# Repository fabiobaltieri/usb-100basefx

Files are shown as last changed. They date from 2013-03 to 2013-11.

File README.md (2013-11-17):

USB to 100BASE-FX
==================

http://fabiobaltieri.com/2013/05/26/usb-to-100base-fx-optical-fiber-network-card/

This project is an Open-Hardware USB to 100BASE-FX fiber optic network card,
based on an ASIX AX88772B USB to Fast Ethernet controller, and comes in two
variants for the fiber transciver.

License
-------

This work is licensed under a Creative Commons Attribution-ShareAlike 3.0
License.

Contents
--------

    README        this file
    docs/         datasheets and documentation
    scsc/         source directory for the 1x9 hardware variant
    sfp/          source directory for the SFP hardware variant
    eeprom-notes  some notes and snippets on device configuration

Hardware
--------

All hardware files (schematic, layout and libraries) are in CadSoft Eagle
format.

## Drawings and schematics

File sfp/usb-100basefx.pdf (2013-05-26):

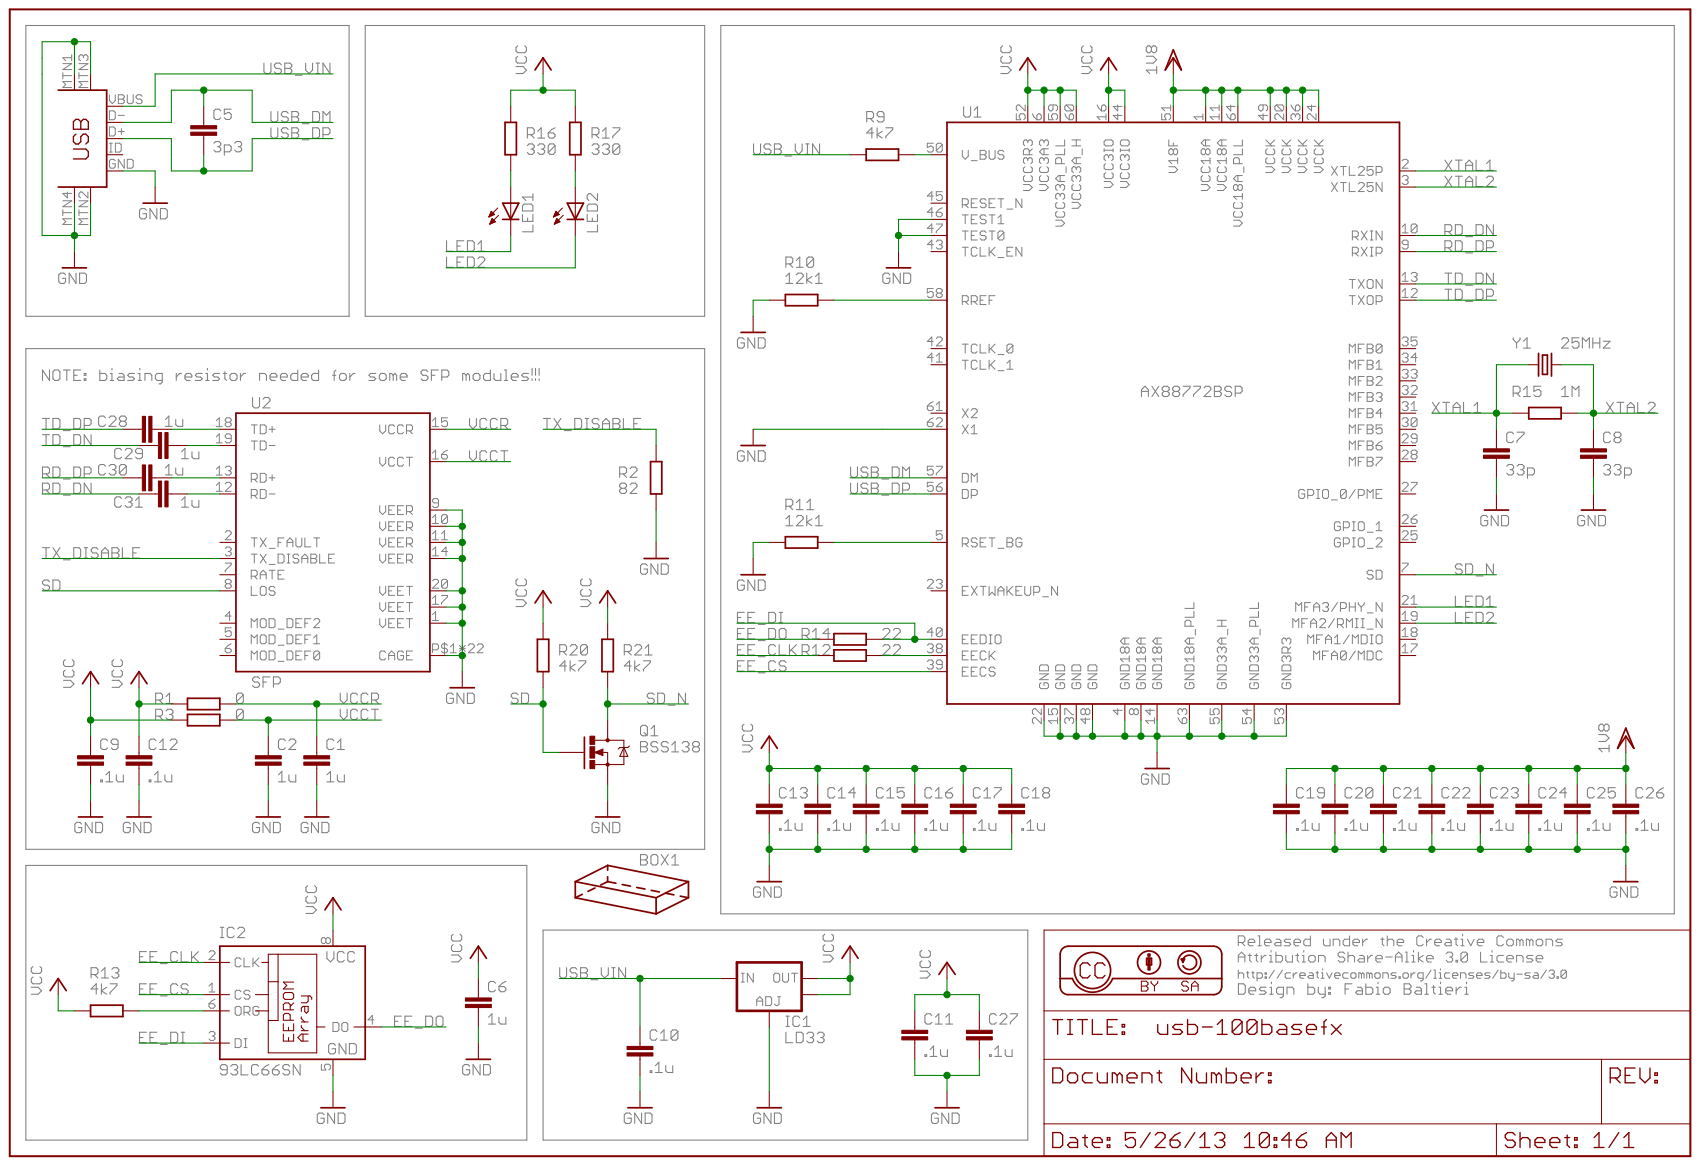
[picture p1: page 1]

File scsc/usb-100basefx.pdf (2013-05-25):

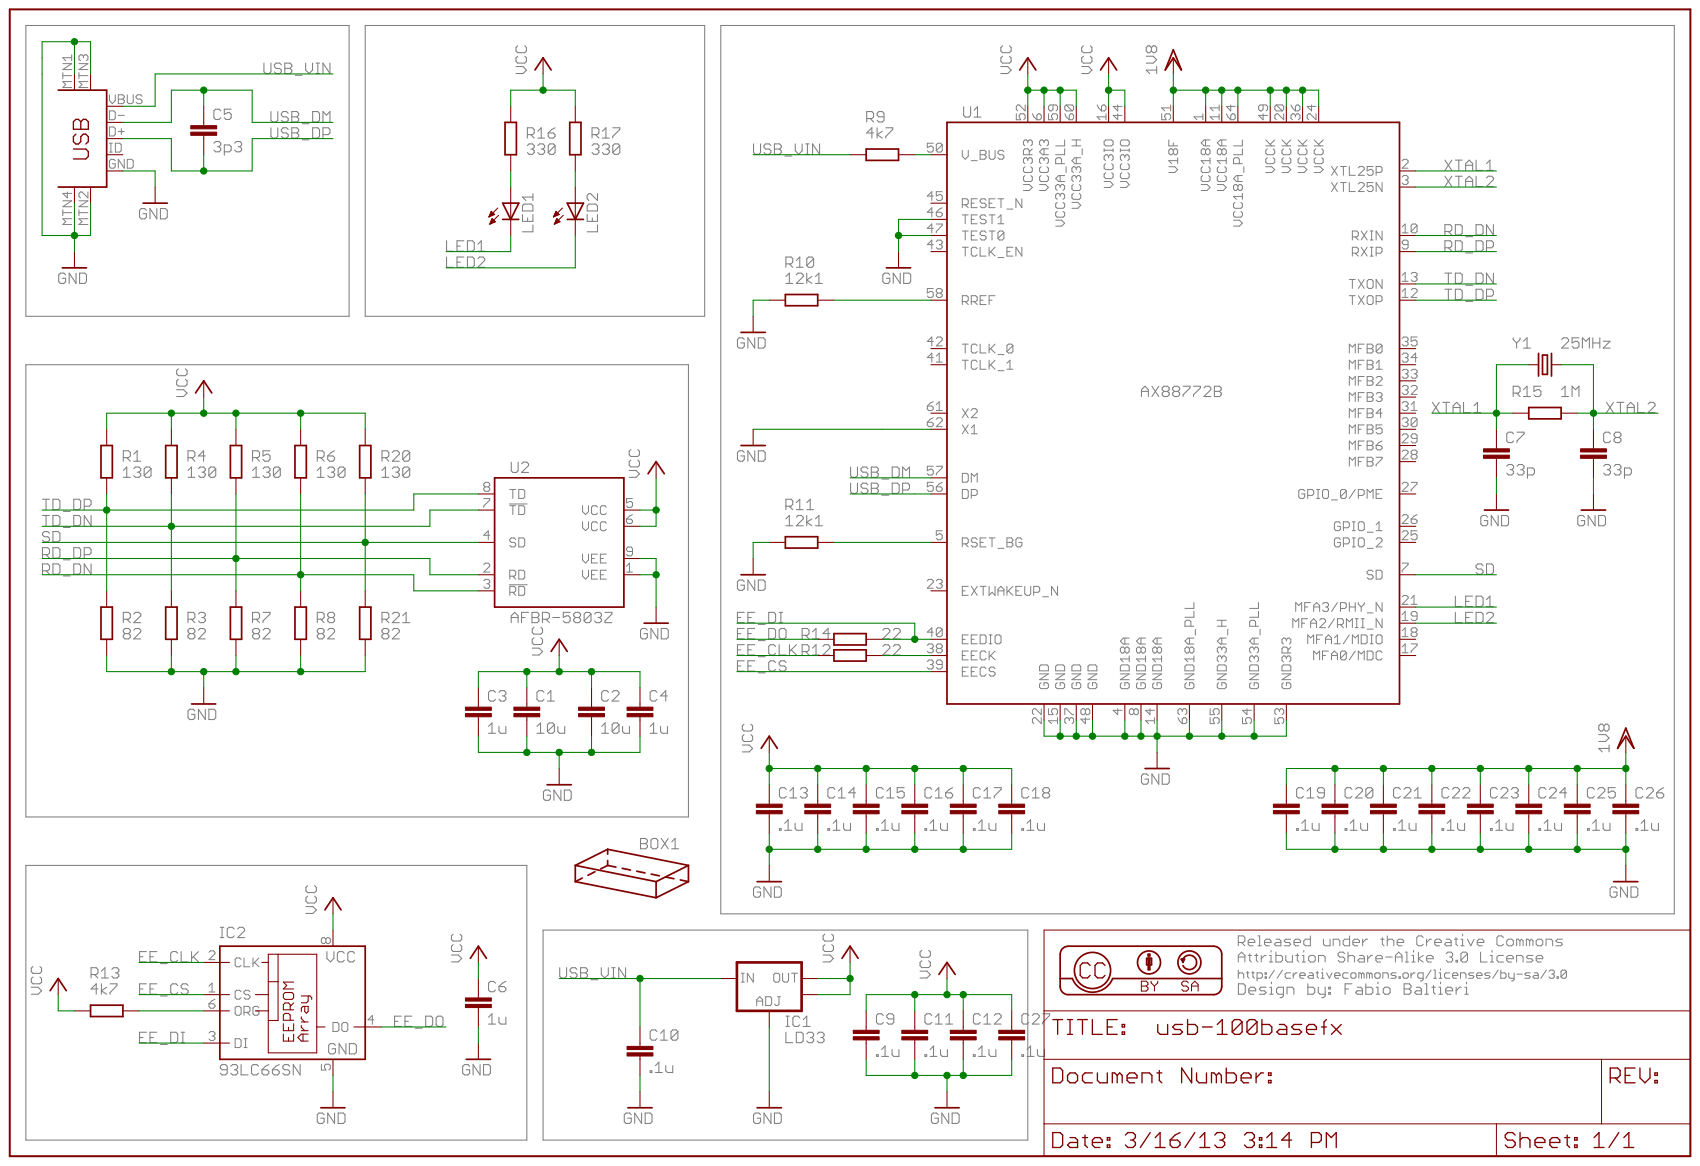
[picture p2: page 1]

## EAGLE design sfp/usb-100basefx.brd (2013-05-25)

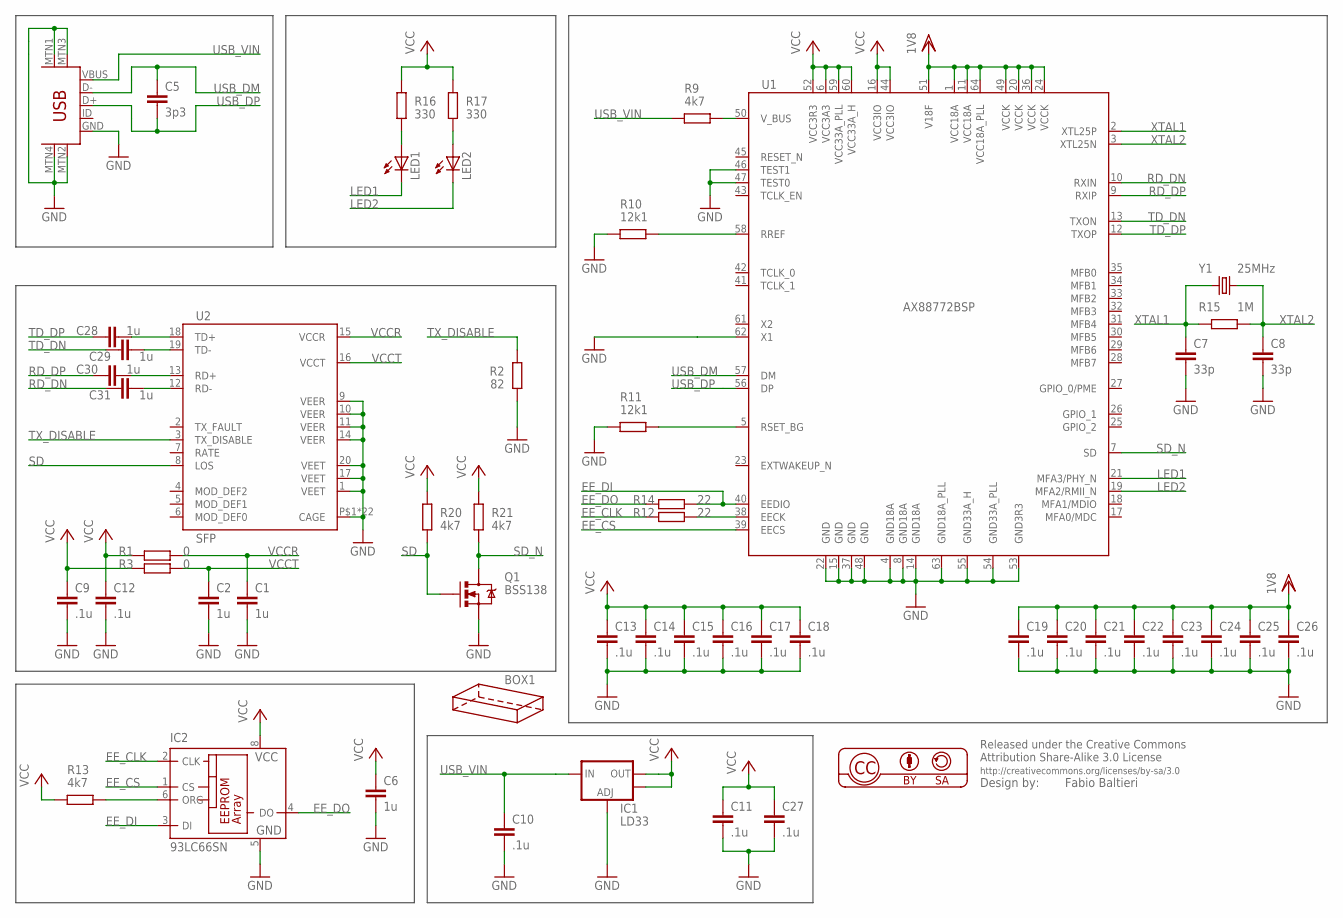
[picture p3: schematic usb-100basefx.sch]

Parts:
BOX1: HAMMOND-BOX-H-1H; 1551H-1HOLE
C1, C2, C6, C28, C29, C30, C31: 1u; C0603
C5: 3p3; C0603
C7, C8: 33p; C0603
C9, C10, C11, C12, C13, C14, C15, C16, C17, C18, C19, C20, C21, C22, C23, C24, C25, C26, C27: .1u; C0603
IC1: LD33; SOT223
IC2: 93LC66SN; SO-08
LED1, LED2: LEDCHIPLED_0805; CHIPLED_0805
Q1: BSS138; SOT23
R1, R3: 0; R0603
R2: 82; R0603
R9, R13, R20, R21: 4k7; R0603
R10, R11: 12k1; R0603
R12, R14: 22; R0603
R15: 1M; R0603
R16, R17: 330; R0603
U1: AX88772BSP; LQFP64-0.4MM-SHORTPAD
U2: SFP
U$1: USB-MINIB-5PIN; USB-MINIB
Y1: 25MHz; CRYSTAL-SMD-5X3

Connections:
EE_CLK: IC2.2 (CLK), R12.1
EE_CS: IC2.1 (CS), U1.39 (EECS)
EE_DI: IC2.3 (DI), R14.2, U1.40 (EEDIO)
EE_DO: IC2.4 (DO), R14.1
GND: C1.2, C2.2, C6.2, C7.2, C8.2, C9.2, C10.2, C11.2, C12.2, C13.2, C14.2, C15.2, C16.2, C17.2, C18.2, C19.2, C20.2, C21.2, C22.2, C23.2, C24.2, C25.2, C26.2, C27.2, IC1.1 (ADJ), IC2.5 (GND), Q1.2 (S), R2.2, R10.1, R11.1, U1.4 (GND18A), U1.8 (GND18A), U1.14 (GND18A), U1.15 (GND), U1.22 (GND), U1.37 (GND), U1.46 (TEST1), U1.47 (TEST0), U1.48 (GND), U1.53 (GND3R3), U1.54 (GND33A_PLL), U1.55 (GND33A_H), U1.62 (X1), U1.63 (GND18A_PLL), U2.1 (VEET), U2.9 (VEER), U2.10 (VEER), U2.11 (VEER), U2.14 (VEER), U2.17 (VEET), U2.20 (VEET), U2.P$1 (CAGE), U2.P$2 (CAGE), U2.P$3 (CAGE), U2.P$4 (CAGE), U2.P$5 (CAGE), U2.P$6 (CAGE), U2.P$7 (CAGE), U2.P$8 (CAGE), U2.P$9 (CAGE), U2.P$10 (CAGE), U2.P$11 (CAGE), U2.P$12 (CAGE), U2.P$13 (CAGE), U2.P$14 (CAGE), U2.P$15 (CAGE), U2.P$16 (CAGE), U2.P$17 (CAGE), U2.P$18 (CAGE), U2.P$19 (CAGE), U2.P$20 (CAGE), U2.P$21 (CAGE), U2.P$22 (CAGE), U$1.GND, U$1.MTN1 (MTN2), U$1.MTN2 (MTN3), U$1.MTN3 (MTN1), U$1.MTN4
LED1: LED1.C, U1.21 (MFA3/PHY_N)
LED2: LED2.C, U1.19 (MFA2/RMII_N)
unnamed: R9.2, U1.50 (V_BUS)
unnamed: R10.2, U1.58 (RREF)
unnamed: R11.2, U1.5 (RSET_BG)
unnamed: R12.2, U1.38 (EECK)
unnamed: IC2.6 (ORG), R13.2
unnamed: LED1.A, R16.2
unnamed: LED2.A, R17.2
unnamed: C29.2, U2.19 (TD-)
unnamed: C28.2, U2.18 (TD+)
unnamed: C30.2, U2.13 (RD+)
unnamed: C31.2, U2.12 (RD-)
RD_DN: C31.1, U1.10 (RXIN)
RD_DP: C30.1, U1.9 (RXIP)
SD: Q1.1 (G), R20.2, U2.8 (LOS)
SD_N: Q1.3 (D), R21.2, U1.7 (SD)
TD_DN: C29.1, U1.13 (TXON)
TD_DP: C28.1, U1.12 (TXOP)
TX_DISABLE: R2.1, U2.3 (TX_DISABLE)
USB_DM: C5.1, U1.57 (DM), U$1.D-
USB_DP: C5.2, U1.56 (DP), U$1.D+
USB_VIN: C10.1, IC1.3 (IN), R9.1, U$1.VBUS
VCC: C6.1, C9.1, C11.1, C12.1, C13.1, C14.1, C15.1, C16.1, C17.1, C18.1, C27.1, IC1.2 (OUT), IC1.4 (OUT), IC2.8 (VCC), R1.1, R3.1, R13.1, R16.1, R17.1, R20.1, R21.1, U1.6 (VCC3A3), U1.16 (VCC3IO), U1.44 (VCC3IO), U1.52 (VCC3R3), U1.59 (VCC33A_PLL), U1.60 (VCC33A_H)
VCCR: C1.1, R1.2, U2.15 (VCCR)
VCCT: C2.1, R3.2, U2.16 (VCCT)
VDD: C19.1, C20.1, C21.1, C22.1, C23.1, C24.1, C25.1, C26.1, U1.1 (VCC18A), U1.11 (VCC18A), U1.20 (VCCK), U1.24 (VCCK), U1.36 (VCCK), U1.49 (VCCK), U1.51 (V18F), U1.64 (VCC18A_PLL)
XTAL1: C7.1, R15.1, U1.2 (XTL25P), Y1.1
XTAL2: C8.1, R15.2, U1.3 (XTL25N), Y1.3 (2)

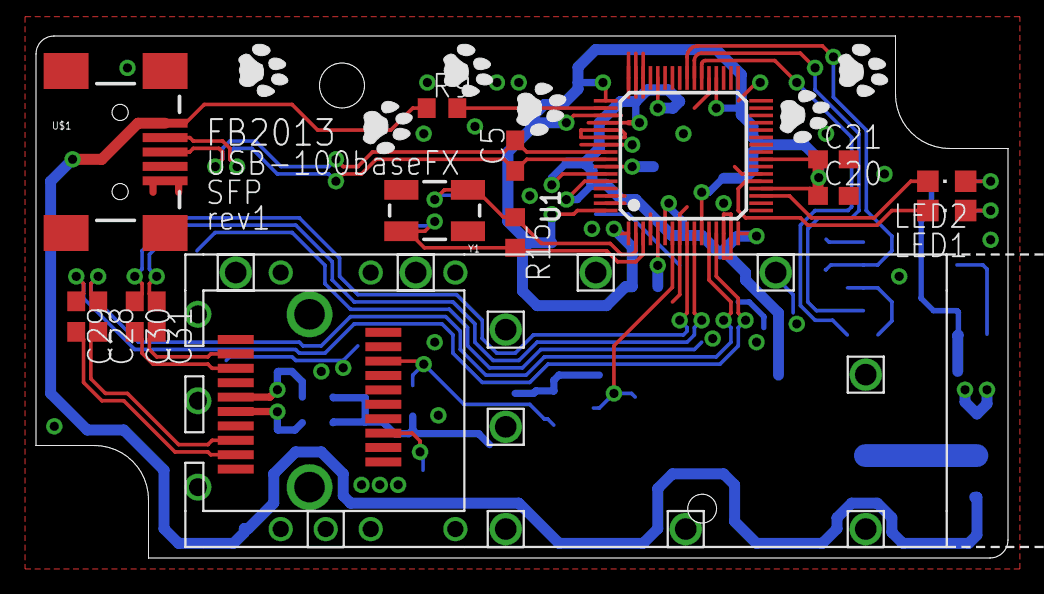
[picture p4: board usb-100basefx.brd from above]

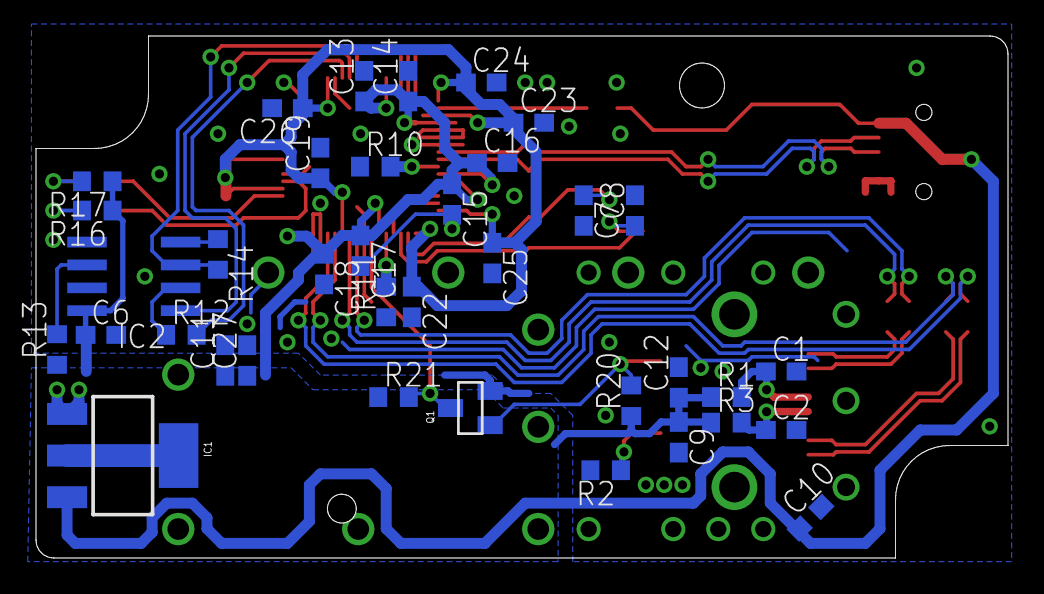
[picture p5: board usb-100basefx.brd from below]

Board: 2 copper layers, 54.0 x 29.0 mm, 59 parts (37 on the bottom side), 34 nets.

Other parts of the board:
U$2, U$4, U$8: CAT-L
U$3, U$5, U$7: CAT-R

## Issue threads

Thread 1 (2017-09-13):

USB to 1000BASE-SX / USB to 10GBASE-SR

robert-scheck, 2017-09-13:
Do you have plans for something like "USB to 1000BASE-SX" or "USB to 10GBASE-SR"? Depending on the exact use case this requires USB 3.1 Gen 2.

fabiobaltieri, 2017-09-13:
Not really. I wanted to do a gigabit version but the only option I've found was a combination of an RGMII Asix chip (the AX88178 I think) plus a Vitesse VSC8211 PHY that goes into SerDes for an SFP module. It should work but the PHY only comes in fairly unfriendly 117 pin rectangular BGA package. Plus the MAC is USB 2.0 only. Too messy...

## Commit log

2012-12-04 hw: use ld1117 for power
    [usb-100basefx.brd, usb-100basefx.sch]
2012-12-09 move usb connector
    [usb-100basefx.brd]
2012-12-15 move scsc version to scsc directory
    [usb-100basefx.brd, usb-100basefx.sch]
2013-01-16 hw-scsc: add some more gnd vias
    [usb-100basefx.brd]
2013-01-19 hw: redone
    [usb-100basefx.brd, usb-100basefx.sch]
2013-01-19 hw: rcx
    [usb-100basefx.brd]
2013-01-20 rc: update
    [usb-100basefx.brd, usb-100basefx.sch]
2013-03-16 hw: change some values
    [usb-100basefx.brd, usb-100basefx.sch]
2013-03-31 add sfp version
    [usb-100basefx.brd, usb-100basefx.sch]
2013-03-31 sfp: fixes
    [usb-100basefx.brd, usb-100basefx.sch]
2013-03-31 add gnd guard
    [usb-100basefx.brd]
2013-03-31 drill to 1.6mm
    [usb-100basefx.brd]
2013-03-31 there's a cat on my pcb...
    [usb-100basefx.brd]
2013-04-04 rev1: fix sd signal logic level
    [usb-100basefx.brd, usb-100basefx.sch]
2013-04-04 sfp: schematic cleanup
    [usb-100basefx.brd, usb-100basefx.sch]
2013-04-04 add some vias and close a ground plane
    [usb-100basefx.brd]
2013-05-25 sfp: change cap to 33p
    [usb-100basefx.brd, usb-100basefx.sch]
2013-05-25 sfp: add bias note
    [usb-100basefx.sch]
2013-05-25 scsc: add pdf schematics
2013-05-25 sfp: add pdf schematics
2013-05-26 sfp: reword biasing note
    [usb-100basefx.sch]

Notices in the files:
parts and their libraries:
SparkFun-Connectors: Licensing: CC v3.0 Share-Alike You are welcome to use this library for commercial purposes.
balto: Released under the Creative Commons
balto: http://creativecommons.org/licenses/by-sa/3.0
